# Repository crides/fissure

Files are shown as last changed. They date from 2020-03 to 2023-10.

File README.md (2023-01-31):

Fissure
=======

My Choc-only split keyboard for desktop use with constant experiments. See below for current keymap

You can find firmware, PCB design and gerber files for past versions if you want to build your own (I'm not used to version controlling PCB files, so if you have problems with them, please let me know). The firmware of this keyboard is based on [QMK firmware](https://github.com/qmk/qmk_firmware). The PCB files are in `pcb/`, and firmwares in `qmk/`.

For a list of all of the past versions, see [here](versions.md). Fun fact: only the first version has 46 keys, which came down to 36 after two weeks of using when I desoldered the top number row.

For a list of past keymaps, you'll have to do it manually as Keyboard Layout Editor doesn't support viewing versions of a keymap. Since the saved keymap is hosted on gist, you can check out [all the past versions of the gist](https://gist.github.com/crides/99409a249d886554bd60af15782b2d50/revisions), copy the contents of each file back into KLE to view the past keymaps.

## Picture of latest version (v3.2)

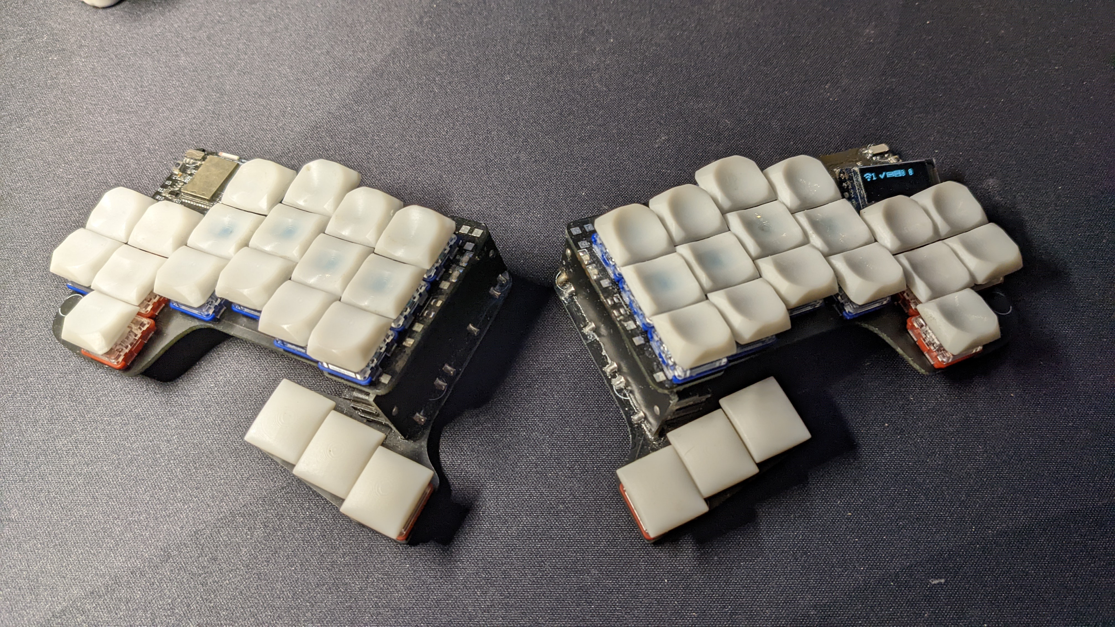
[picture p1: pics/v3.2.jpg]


## Latest Keymap

(generated using <https://github.com/caksoylar/keymap-drawer> with tweaked colors, source is in [keymap.yaml](./keymap.yaml). Note the existence of the lower outer pinky keys is a limitation of the graphic generator. [equivalent version on KLE](http://www.keyboard-layout-editor.com/#/gists/99409a249d886554bd60af15782b2d50))



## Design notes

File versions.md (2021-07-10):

# Versions

## Version 3 - low profile?

Technically none of the version 3 boards are truly 36 key, as they are 20 key reversible PCBs. However only the 2 extra on the right side are meant to be used, and they are only for stenography. So practically this can be considered a 36 key.

For v3.1 and above I have written a [build guide](build-v3.1+.md) as the design is not exactly focused on the ease to build.

### Version 3.1

The PCB construction on v3.0 is too complex for having 2 different vertical supports, and prone to unbalancing. In 3.1 this was changed to only 1 long vertical support, so that there are fewer PCB pieces needed, and balancing becomes much easier. The connector has been changed to flat solder-only connectors, as it's hard for pegs and holes to be aligned, connected, and be clean on the outside. The tenting has also been increased to 20mm instead of 15mm. I also attempted to make the board more compact by moving the TRRS connector and OLED screen. The latter was moved to the board connector in the middle as a experiment. The promicro has been moved below the board, as there are more room there, making it look better on the outside.

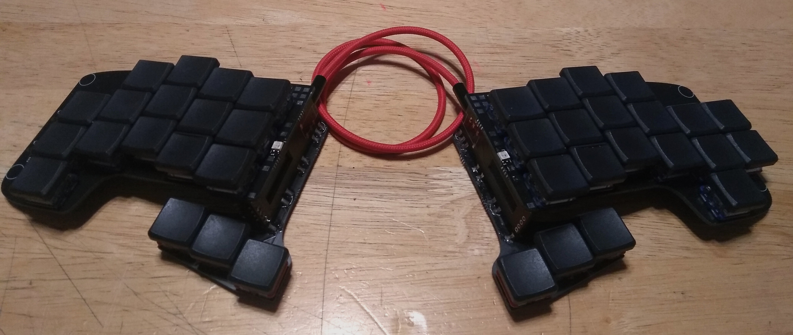
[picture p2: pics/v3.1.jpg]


### Version 3.0

As I find tented boards to be more comfortable (my palms have never been horizontal when I type), this is an attempt at a board that "automatically tents" and have different heights for the thumb and fingers. I also integrated [embedded steno](https://github.com/crides/steno) and thus the 2 added pinky switches (they are only used on the right side, as you can tell from the pictures) and the OLED for displaying the current stroke.

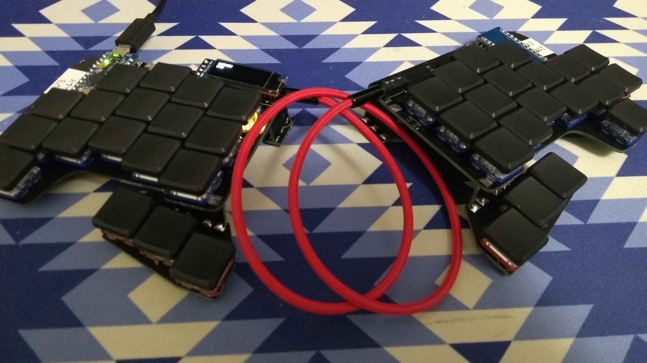
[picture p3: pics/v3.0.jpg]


## Version 2 - going smaller

A 36 key columnar-staggered version. I removed the nubmer row cuz I have dropped it in version 1. A SK6812 mini is added for status display.

The gerber files for version 2 is in a separate folder (I still need to get used to version control with external-software-managed files).

### Version 2.1

I decided that Logitech Unifying wireless is not usabily-possible, so that was dropped. Pinky stagger was increased by 2mm, and thumb cluster was rotated by 90degs so that they are closer together. Spacing was finally changed to choc spacing (17x18mm). A joystick footprint was added, but was never used due to the high force required to move the stick, and dropping 1 thumb button was quite time consuming

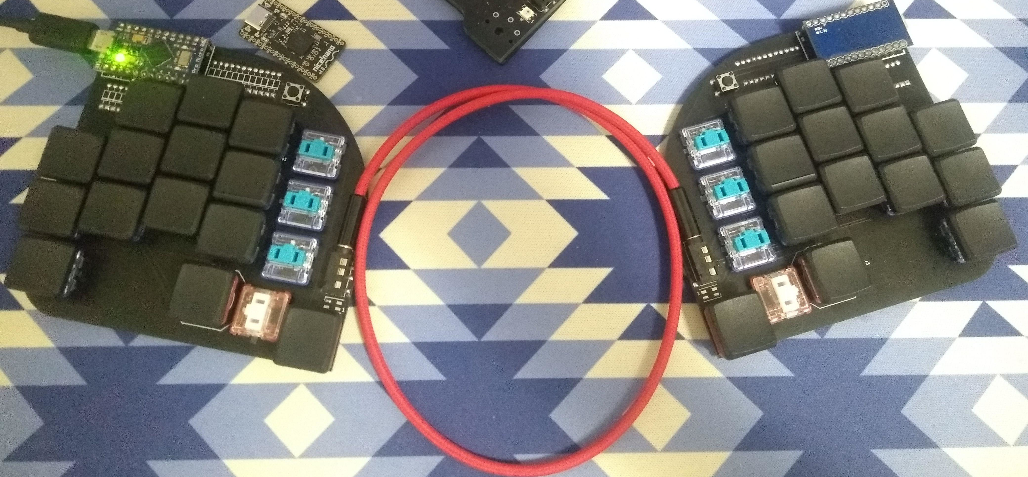
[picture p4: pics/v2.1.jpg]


### Version 2.0

I wanted to go wireless with this version, and so I added a 2x4 header footprint for a nRF24 module (for potential use with a Logitech Unifying Receiver) and a coincell localtion. Spacing was changed to slightly-above-choc (i.e. 17.5x18.5mm).

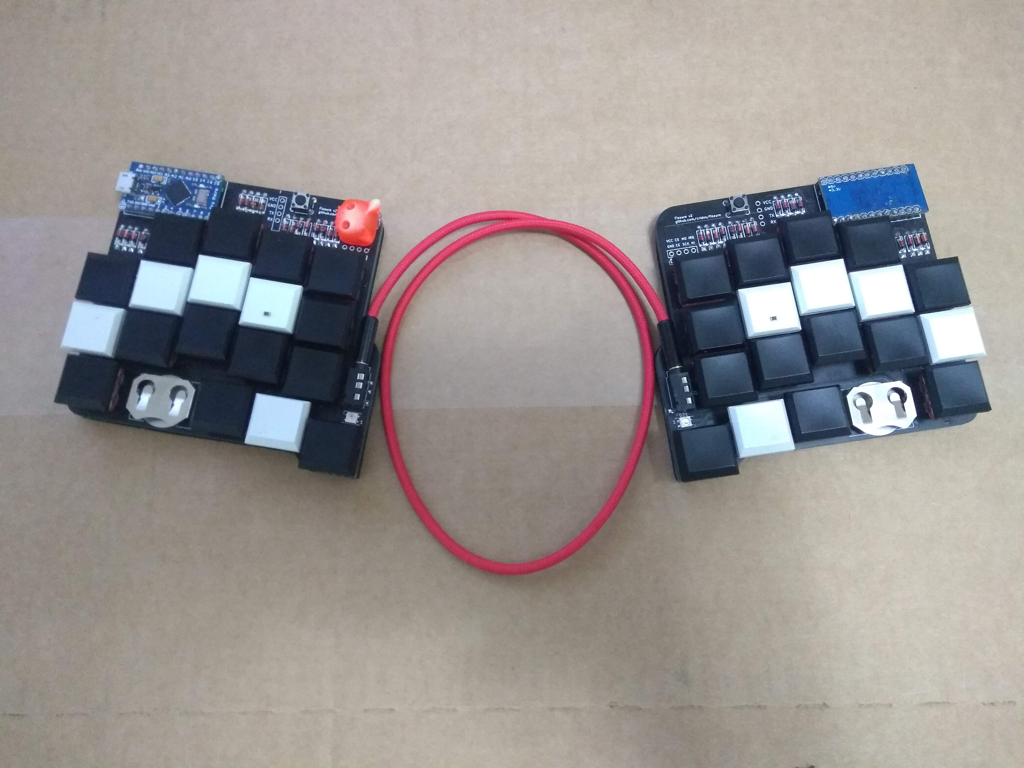
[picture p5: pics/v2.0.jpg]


## Version 1 - the start

A 46-key split keyboard that combined (in version 1) the ideas of [5plit](https://oddrocketkeyboards.blogspot.com/2018/05/5plit-v2.html) and [for science](https://github.com/peej/for-science-keyboard). This was my first ever mechanical keyboard, and I decided to go with a slightly more common layout (orthogonal & 46 key with a number row). However I quickly got rid of the number row, because it's hard for my fingers to easily reach it. It also uses MX spacing, which I quickly decided was too wide. I also botched on a RGB LED for status display.

Only firmware and gerber files are currently available, as I lost my design files when I accidentally deleted them (and I used no VCS at that time :)).

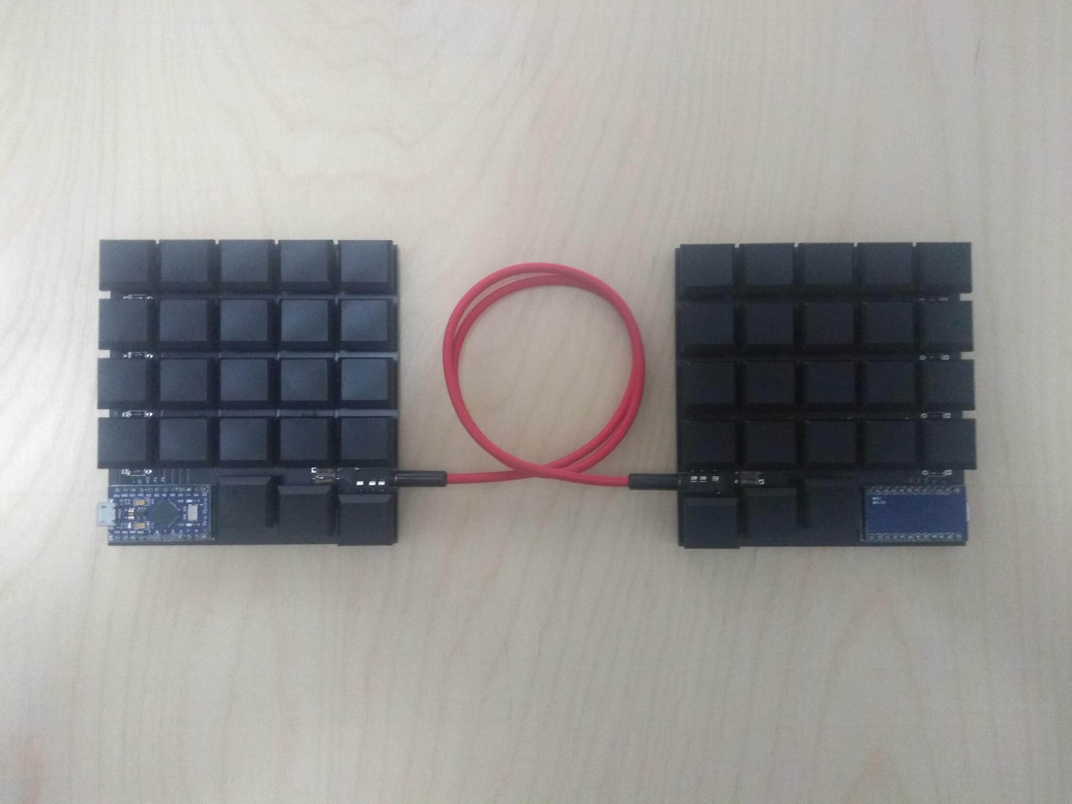
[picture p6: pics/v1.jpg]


[keymap](http://www.keyboard-layout-editor.com/#/gists/f470cb5798ff4dc8b27f680a605061f3).

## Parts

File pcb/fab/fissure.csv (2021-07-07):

Comment | Designator | Footprint | LCSC Part #
10nF | C1 | C_0603_1608Metric
BLUE | D1 | LED_1206_3216Metric
1N5819 | D3 | D_SOD-323
RED | D5 | LED_1206_3216Metric
USB_C_Receptacle_USB2.0 | J2 | USB_C_Receptacle_HRO_TYPE-C-31-M-12
AO3401A | Q1,Q2 | SOT-23
10k | R10 | R_0603_1608Metric
2M | R11 | R_0603_1608Metric
100k | R12 | R_0603_1608Metric
5.1M | R5,R8 | R_0603_1608Metric
1k | R6,R4 | R_0603_1608Metric
5.1k | R7,R9 | R_0603_1608Metric
SW_Push | SW1 | SW_SPST_B3U-1000P
SW_SPDT | SW4 | SW_SPDT_PCM12
LTC4054ES5-4.2 | U3 | TSOT-23-5
MCP1700-3302E_SOT23 | U4 | SOT-23

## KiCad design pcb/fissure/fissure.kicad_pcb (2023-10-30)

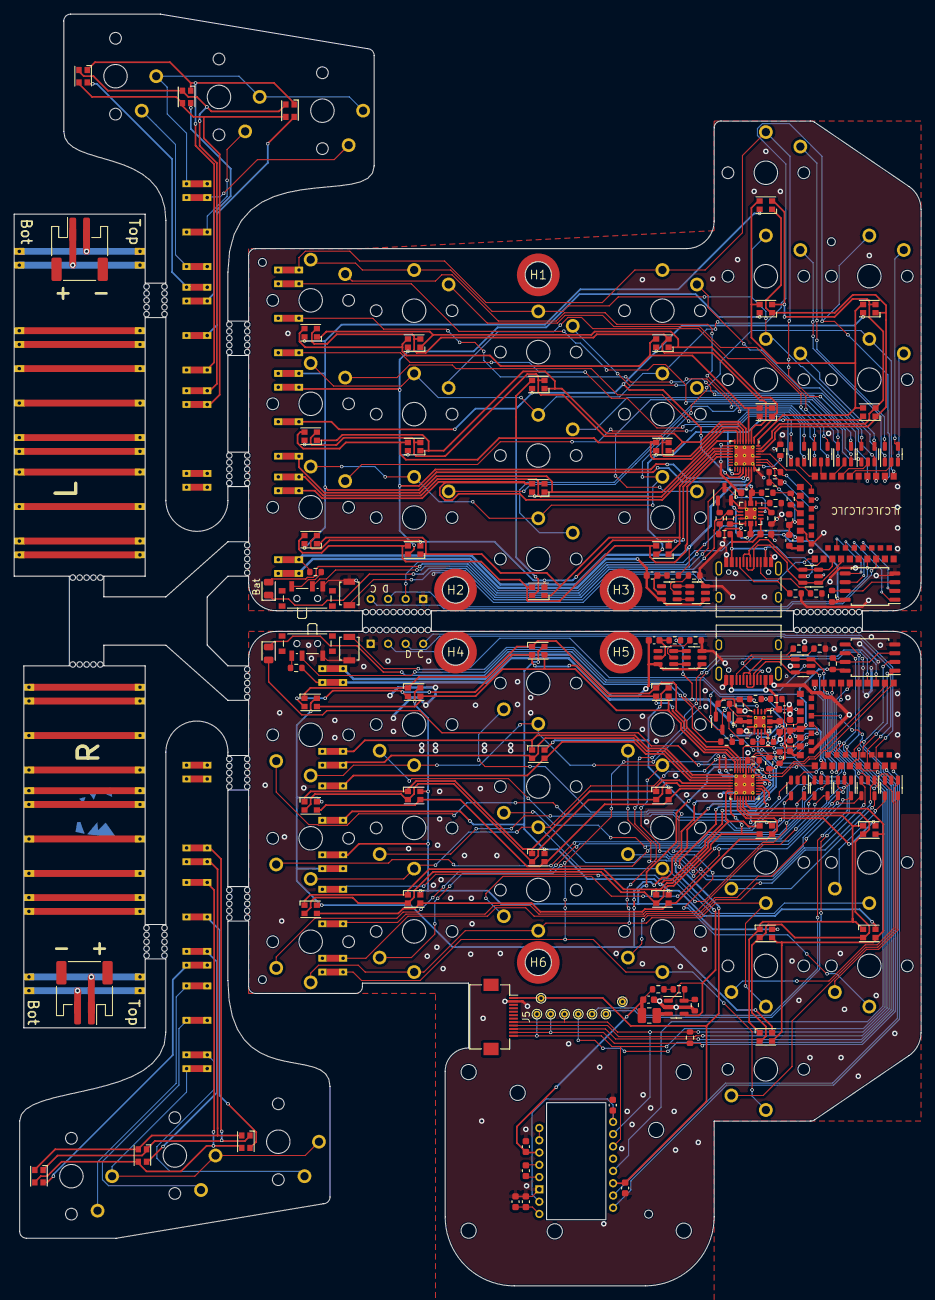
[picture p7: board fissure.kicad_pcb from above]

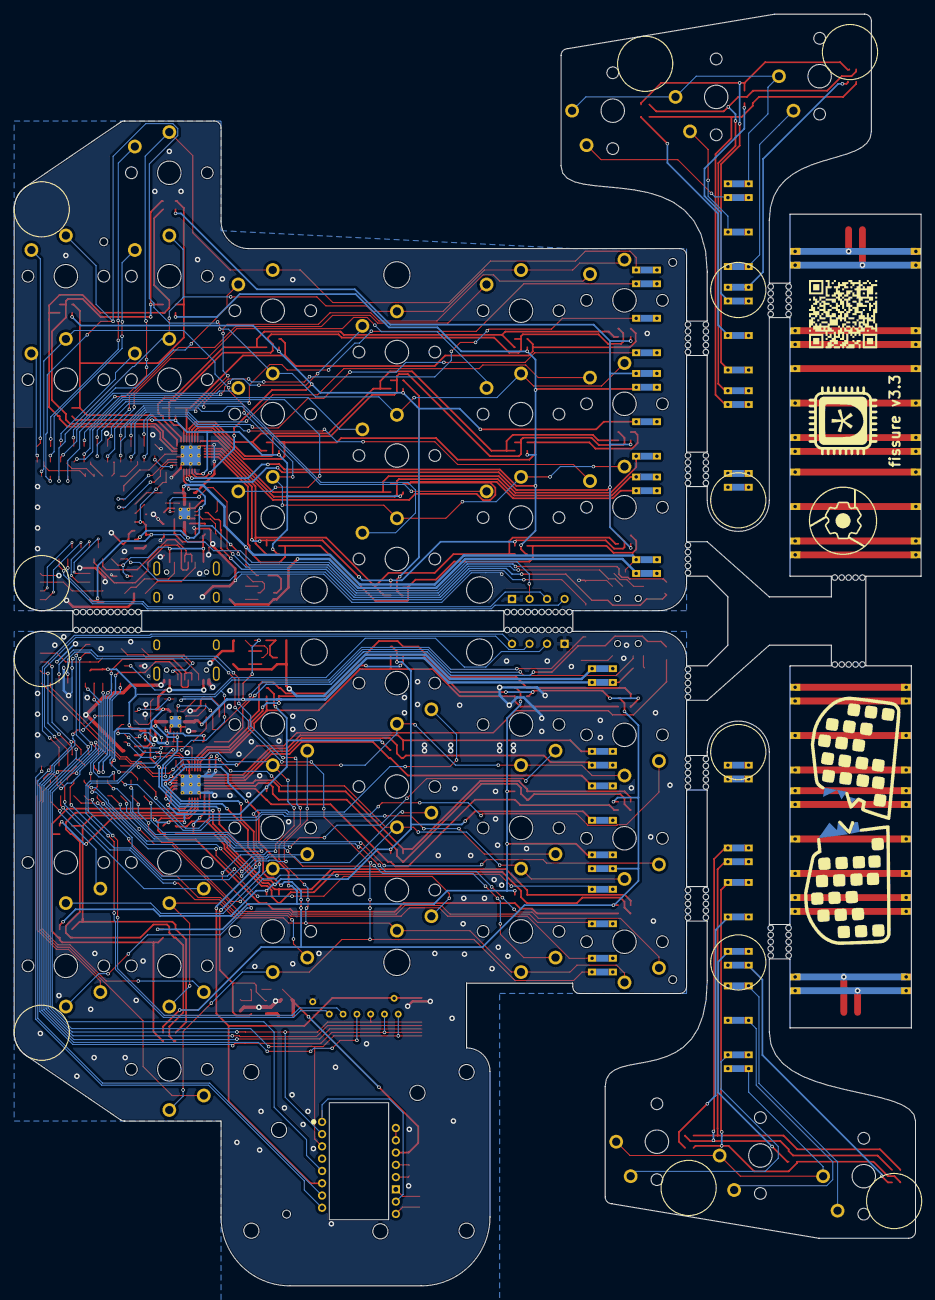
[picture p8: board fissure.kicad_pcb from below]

Board: 2 copper layers, 131.5 x 184.4 mm, 200 parts (6 on the bottom side), 228 nets.

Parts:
BT1, BT2: Battery_Cell; JST_PH_S2B-PH-SM4-TB_1x02-1MP_P2.00mm_Horizontal
C1, C2, C3, C4, C5, C13, C14, C15: 4.7uF; C_0603_1608Metric
C6, C7, C8: 100nF; C_0603_1608Metric
C9, C11: 10nF; C_0603_1608Metric
C10, C12: 10uF; C_0603_1608Metric
C16, C17: 0.1uF; C_0603_1608Metric
D1, D2: RED; LED_0805_2012Metric
D3, D4, D5, D6, D7, D8, D9, D10, D11, D12: 1SS309; SOT-23-5
H1, H2, H3, H4, H5, H6: M2
J1, J9: debug-port; debug-port-single-side
J2, J8: USB_C_Receptacle_USB2.0; USB_C_Receptacle_HRO_TYPE-C-31-M-12
J3, J4, J12, J16: Conn_01x12_Pin; bridge-conn
J5: cirque-trackpad; Hirose_FH12-12S-0.5SH_1x12-1MP_P0.50mm_Horizontal
J6, J7, J11, J17: Conn_01x12_Socket; bridge
K1, K6, K11, K16, K17, K25, K30, K35, K36, K37: diode-choc; pg1350-SN
K2, K5, K7, K10, K12, K15, K22, K27, K32: diode-choc; pg1350-SL
K3, K8, K13, K18, K19, K20, K23, K28, K33, K38, K39, K40: diode-choc; pg1350-S
K4, K9, K14, K21, K24, K26, K29, K31, K34: diode-choc; pg1350-SR
L1, L3: 10uH; L_0603_1608Metric
L2: 2.2uH; L_1008_2520Metric
LED1, LED2, LED3, LED4, LED5, LED6, LED7, LED8, LED9, LED10, LED11, LED12, LED13, LED14, LED15, LED16, LED17, LED18, LED19, LED20, LED21, LED22, LED23, LED24, LED25, LED26, LED27, LED28, LED29, LED30, LED31, LED32, LED33, LED34, LED35, LED36, LED37, LED38, LED39, LED40: LED_BGRA; LED_ASMB-KTF0-0A306
Q1, Q2: AO3400A; SOT-23
QR*****: github
R1, R2, R4, R15, R16, R22, R23: 10k; R_0603_1608Metric
R3, R5, R8, R10, R11, R12, R18, R19, R20, R21, R24, R25, R26: 100k; R_0603_1608Metric
R6, R17, R27, R28, R33, R34: 1k; R_0603_1608Metric
R7, R9, R13, R14, R29, R30, R35, R36: 5.1k; R_0603_1608Metric
R31, R32: 100; R_0603_1608Metric
SW1, SW2: SW_Push; SW_SPST_B3U-1000P
SW3, SW4: SW_SPDT; SW_SPDT_PCM12
TP1: CS; TestPoint_THTPad_D1.0mm_Drill0.5mm
TP2: SCLK; TestPoint_THTPad_D1.0mm_Drill0.5mm
TP3: MISO; TestPoint_THTPad_D1.0mm_Drill0.5mm
TP4: MOSI; TestPoint_THTPad_D1.0mm_Drill0.5mm
TP5: SDA; TestPoint_THTPad_D1.0mm_Drill0.5mm
TP6: SCL; TestPoint_THTPad_D1.0mm_Drill0.5mm
TP7: 3V3; TestPoint_THTPad_D1.0mm_Drill0.5mm
TP8: GND; TestPoint_THTPad_D1.0mm_Drill0.5mm
U1, U12: e73-2gm08s1c; e73-2g4m08s1c-shrunk
U2, U10: W25Q128JVS; SOIC-8_5.23x5.23mm_P1.27mm
U3, U9: BQ24075; VQFN-16-1EP_3x3mm_P0.5mm_EP1.68x1.68mm_ThermalVias
U4: TLV62568DBV; SOT-23-5
U5: PMW3610
U6, U13: IS31FL3729; QFN-32-1EP_4x4mm_P0.4mm_EP2.9x2.9mm_ThermalVias
U7, U8: SRV05-4; SOT-23-6
U11, U14: DW01A; SOT-23-6
U15, U16: FS8205; SOT-23-6

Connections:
+1V8: C7.2, C12.2, L2.2, R10.1, U5.14 (VDD)
/power_l/BAT_PULLUP: R21.1, SW4.1 (A)
/power_l/SYSOFF: Q1.3 (D), SW4.2 (B), U3.15 (SYSOFF)
/power_l/~PGOOD: R25.1, R27.1, U3.7 (~PGOOD)
/power_r/BAT_PULLUP: R24.1, SW3.3 (C)
/power_r/SYSOFF: Q2.3 (D), SW3.2 (B), U9.15 (SYSOFF)
/power_r/~PGOOD: R26.1, R28.1, U9.7 (~PGOOD)
/thumb+led_l/A0: LED1.4 (A), LED2.4 (A), LED7.4 (A), LED8.4 (A), LED16.4 (A), U6.19 (SW4)
/thumb+led_l/A1: J3.7, LED3.4 (A), LED12.4 (A), LED13.4 (A), LED17.4 (A), U6.20 (SW3)
/thumb+led_l/A2: J3.6, LED4.4 (A), LED6.4 (A), LED9.4 (A), LED14.4 (A), U6.21 (SW2)
/thumb+led_l/A3: J3.5, LED5.4 (A), LED10.4 (A), LED11.4 (A), LED15.4 (A), U6.22 (SW1)
/thumb+led_l/B0: LED6.1 (BK), LED11.1 (BK), LED16.1 (BK), LED17.1 (BK), U6.30 (CS1)
/thumb+led_l/B1: LED1.1 (BK), LED12.1 (BK), LED14.1 (BK), LED15.1 (BK), U6.1 (CS4)
/thumb+led_l/B2: LED7.1 (BK), LED9.1 (BK), LED10.1 (BK), LED13.1 (BK), U6.4 (CS7)
/thumb+led_l/B3: LED2.1 (BK), LED3.1 (BK), LED4.1 (BK), LED5.1 (BK), U6.11 (CS13)
/thumb+led_l/B4: J3.8, LED8.1 (BK), U6.7 (CS10)
/thumb+led_l/G0: LED6.2 (GK), LED11.2 (GK), LED16.2 (GK), LED17.2 (GK), U6.31 (CS2)
/thumb+led_l/G1: LED1.2 (GK), LED12.2 (GK), LED14.2 (GK), LED15.2 (GK), U6.2 (CS5)
/thumb+led_l/G2: LED7.2 (GK), LED9.2 (GK), LED10.2 (GK), LED13.2 (GK), U6.5 (CS8)
/thumb+led_l/G3: LED2.2 (GK), LED3.2 (GK), LED4.2 (GK), LED5.2 (GK), U6.12 (CS14)
/thumb+led_l/G4: J3.9, LED8.2 (GK), U6.8 (CS11)
/thumb+led_l/R0: LED6.3 (RK), LED11.3 (RK), LED16.3 (RK), LED17.3 (RK), U6.32 (CS3)
/thumb+led_l/R1: LED1.3 (RK), LED12.3 (RK), LED14.3 (RK), LED15.3 (RK), U6.3 (CS6)
/thumb+led_l/R2: LED7.3 (RK), LED9.3 (RK), LED10.3 (RK), LED13.3 (RK), U6.6 (CS9)
/thumb+led_l/R3: LED2.3 (RK), LED3.3 (RK), LED4.3 (RK), LED5.3 (RK), U6.13 (CS15)
/thumb+led_l/R4: J3.10, LED8.3 (RK), U6.10 (CS12)
/thumb+led_l/T_A1: J4.7, LED20.4 (A)
/thumb+led_l/T_A2: J4.6, LED19.4 (A)
/thumb+led_l/T_A3: J4.5, LED18.4 (A)
/thumb+led_l/T_B4: J4.8, LED18.1 (BK), LED19.1 (BK), LED20.1 (BK)
/thumb+led_l/T_G4: J4.9, LED18.2 (GK), LED19.2 (GK), LED20.2 (GK)
/thumb+led_l/T_R4: J4.10, LED18.3 (RK), LED19.3 (RK), LED20.3 (RK)
/thumb+led_r/A0: LED24.4 (A), LED25.4 (A), LED28.4 (A), LED29.4 (A), LED37.4 (A), U13.19 (SW4)
/thumb+led_r/A1: J12.7, LED23.4 (A), LED33.4 (A), LED34.4 (A), LED36.4 (A), U13.20 (SW3)
/thumb+led_r/A2: J12.6, LED22.4 (A), LED27.4 (A), LED30.4 (A), LED32.4 (A), U13.21 (SW2)
/thumb+led_r/A3: J12.5, LED21.4 (A), LED26.4 (A), LED31.4 (A), LED35.4 (A), U13.22 (SW1)
/thumb+led_r/B0: LED21.1 (BK), LED22.1 (BK), LED23.1 (BK), LED24.1 (BK), U13.30 (CS1)
/thumb+led_r/B1: LED26.1 (BK), LED27.1 (BK), LED29.1 (BK), LED33.1 (BK), U13.4 (CS7)
/thumb+led_r/B2: LED25.1 (BK), LED31.1 (BK), LED32.1 (BK), LED34.1 (BK), U13.7 (CS10)
/thumb+led_r/B3: LED30.1 (BK), LED35.1 (BK), LED36.1 (BK), LED37.1 (BK), U13.11 (CS13)
/thumb+led_r/B4: J12.10, LED28.1 (BK), U13.1 (CS4)
/thumb+led_r/G0: LED21.2 (GK), LED22.2 (GK), LED23.2 (GK), LED24.2 (GK), U13.31 (CS2)
/thumb+led_r/G1: LED26.2 (GK), LED27.2 (GK), LED29.2 (GK), LED33.2 (GK), U13.5 (CS8)
/thumb+led_r/G2: LED25.2 (GK), LED31.2 (GK), LED32.2 (GK), LED34.2 (GK), U13.8 (CS11)
/thumb+led_r/G3: LED30.2 (GK), LED35.2 (GK), LED36.2 (GK), LED37.2 (GK), U13.12 (CS14)
/thumb+led_r/G4: J12.9, LED28.2 (GK), U13.2 (CS5)
/thumb+led_r/R0: LED21.3 (RK), LED22.3 (RK), LED23.3 (RK), LED24.3 (RK), U13.32 (CS3)
/thumb+led_r/R1: LED26.3 (RK), LED27.3 (RK), LED29.3 (RK), LED33.3 (RK), U13.6 (CS9)
/thumb+led_r/R2: LED25.3 (RK), LED31.3 (RK), LED32.3 (RK), LED34.3 (RK), U13.10 (CS12)
/thumb+led_r/R3: LED30.3 (RK), LED35.3 (RK), LED36.3 (RK), LED37.3 (RK), U13.13 (CS15)
/thumb+led_r/R4: J12.8, LED28.3 (RK), U13.3 (CS6)
/thumb+led_r/T_A1: J16.7, LED40.4 (A)
/thumb+led_r/T_A2: J16.6, LED39.4 (A)
/thumb+led_r/T_A3: J16.5, LED38.4 (A)
/thumb+led_r/T_B4: J16.10, LED38.1 (BK), LED39.1 (BK), LED40.1 (BK)
/thumb+led_r/T_G4: J16.9, LED38.2 (GK), LED39.2 (GK), LED40.2 (GK)
/thumb+led_r/T_R4: J16.8, LED38.3 (RK), LED39.3 (RK), LED40.3 (RK)
L_3V3: C1.1, J1.2 (3V3), L3.2, R3.2, R29.2, R30.2, U2.8 (VCC), U12.19 (VDD)
L_BAT+: C4.1, J3.11, R5.1, R21.2, R31.2, U3.2 (BAT), U3.3 (BAT)
L_BAT-: C16.2, J3.12, U11.6 (VSS), U15.1 (S1)
L_BAT_MEAS: R5.2, R8.1, U12.15 (A3_P0.05)
L_BAT_MEAS_EN: R8.2, U12.17 (P1.09)
L_COL0: D3.2 (K), U12.6 ([L]_P1.13)
L_COL1: D4.2 (K), U12.7 ([L]_A0_P0.02)
L_COL2: D5.2 (K), U12.8 ([L]_A5_P0.29)
L_COL3: D6.2 (K), U12.9 ([L]_A7_P0.31)
L_COL4: D7.2 (K), U12.10 ([L]_A6_P0.30)
L_CS: U2.1 (~CS), U12.34 (P0.22)
L_D+: J2.A6 (D+), J2.B6 (D+), U8.1 (IO1), U8.6 (IO4), U12.31 (D+)
L_D-: J2.A7 (D-), J2.B7 (D-), U8.3 (IO2), U8.4 (IO3), U12.29 (D-)
L_GND: C1.2, C2.2, C3.1, C4.2, C5.2, C6.1, C7.1, C9.2, C10.2, C11.2, C12.1, C13.2, C14.1, C15.2, J1.1 (GND), J2.A1 (GND), J2.A12 (GND), J2.B1 (GND), J2.B12 (GND), J5.2 (GND), J8.A1 (GND), J8.A12 (GND), J8.B1 (GND), J8.B12 (GND), J9.1 (GND), Q1.2 (S), Q2.2 (S), R1.2, R2.2, R7.1, R9.1, R12.1, R13.1, R14.1, R15.2, R16.2, R22.1, R23.1, R33.2, R34.2, SW1.2, SW2.2, SW3.1 (A), SW4.3 (C), TP8.1, U1.5 (GND), U1.21 (GND), U1.24 (GND), U2.4 (GND), U3.4 (~CE), U3.5 (EN2), U3.8 (VSS), U3.17 (PAD), U4.2 (GND), U5.11 (GND), U6.9 (GND), U6.24 (GND), U6.28 (AD), U6.33 (GND), U7.2 (VN), U8.2 (VN), U9.4 (~CE), U9.5 (EN2), U9.8 (VSS), U9.17 (PAD), U10.4 (GND), U12.5 (GND), U12.21 (GND), U12.24 (GND), U13.9 (GND), U13.24 (GND), U13.28 (AD), U13.33 (GND), U15.3 (S2), U16.3 (S2)
L_LED_SHDN: U6.29 (~SDB), U12.12 (P0.26)
L_MISO: U2.2 (DO(IO1)), U12.36 (P1.00)
L_MOSI: U2.5 (DI(IO0)), U12.30 (P0.17)
L_ROW0: K2.1, K3.1, K4.1, K5.1, K16.1, U12.1 ([L]_P1.11)
L_ROW1: K7.1, K8.1, K9.1, K10.1, K17.1, U12.2 ([L]_P1.10)
L_ROW2: K1.1, K6.1, K13.1, K14.1, K15.1, U12.3 ([L]_A1_P0.03)
L_ROW3: J3.1, K11.1, K12.1, U12.4 ([L]_A4_P0.28)
L_RST: SW1.1, U12.26 (Reset/P0.18)
L_SCL: R30.1, U6.27 (SCL), U12.14 (P0.06)
L_SCLK: U2.6 (CLK), U12.32 (P0.20)
L_SDA: R29.1, U6.26 (SDA), U12.16 (P0.08)
L_SWC: J1.4 (SWC), U12.39 (SWC)
L_SWD: J1.3 (SWD), U12.37 (SWD)
L_VBUS: C2.1, J2.A4 (VBUS), J2.A9 (VBUS), J2.B4 (VBUS), J2.B9 (VBUS), R25.2, U3.13 (IN), U8.5 (VP), U12.27 (VBUS)
L_VDDH: C3.2, D1.2 (A), U3.6 (EN1), U3.10 (OUT), U3.11 (OUT), U6.23 (VCC), U12.23 (VDDH)
MOTION: U1.43 ([L]_P0.10), U5.8 (MOTION)
MOUSE_~CS: U1.28 (P0.15), U5.5 (~CS)
MOUSE_~RST: U1.41 ([L]_P0.09), U5.7 (~RESET)
unnamed: BT1.1 (+), J6.11, J7.11
unnamed: BT1.2 (-), J6.12, J7.12
unnamed: BT2.1 (+), J11.11, J17.11
unnamed: BT2.2 (-), J11.12, J17.12
unnamed: D1.1 (K), R6.2
unnamed: D2.1 (K), R17.2
unnamed: D3.1 (A), K6.2
unnamed: D3.3 (A), K16.2
unnamed: D3.4 (A), K17.2
unnamed: D3.5 (A), K11.2
unnamed: D4.1 (A), K2.2
unnamed: D4.3 (A), K7.2
unnamed: D4.4 (A), K1.2
unnamed: D4.5 (A), K12.2
unnamed: D5.1 (A), K3.2
unnamed: D5.3 (A), K8.2
unnamed: D5.4 (A), K13.2
unnamed: D5.5 (A), J3.2
unnamed: D6.1 (A), K4.2
unnamed: D6.3 (A), K9.2
unnamed: D6.4 (A), K14.2
unnamed: D6.5 (A), J3.3
unnamed: D7.1 (A), K5.2
unnamed: D7.3 (A), K10.2
unnamed: D7.4 (A), K15.2
unnamed: D7.5 (A), J3.4
unnamed: D8.1 (A), K23.2
unnamed: D8.3 (A), K28.2
unnamed: D8.4 (A), K33.2
unnamed: D8.5 (A), J12.2
unnamed: D9.1 (A), K22.2
unnamed: D9.3 (A), K27.2
unnamed: D9.4 (A), K32.2
unnamed: D9.5 (A), J12.3
unnamed: D10.1 (A), K31.2
unnamed: D10.3 (A), K21.2
unnamed: D10.4 (A), K26.2
unnamed: D10.5 (A), J12.4
unnamed: D11.1 (A), K35.2
unnamed: D11.3 (A), K30.2
unnamed: D11.4 (A), K36.2
unnamed: D11.5 (A), K37.2
unnamed: D12.1 (A), K34.2
unnamed: D12.3 (A), K29.2
unnamed: D12.4 (A), K24.2
unnamed: D12.5 (A), K25.2
unnamed: J2.A5 (CC1), R7.2
unnamed: J2.B5 (CC2), R9.2
unnamed: J4.1, K18.1, K19.1, K20.1
unnamed: J4.2, K20.2
unnamed: J4.3, K19.2
unnamed: J4.4, K18.2
unnamed: J6.1, J7.1
unnamed: J6.2, J7.2
unnamed: J6.3, J7.3
unnamed: J6.4, J7.4
unnamed: J6.5, J7.5
unnamed: J6.6, J7.6
unnamed: J6.7, J7.7
unnamed: J6.8, J7.8
unnamed: J6.9, J7.9
unnamed: J6.10, J7.10
unnamed: J8.A5 (CC1), R13.2
unnamed: J8.B5 (CC2), R14.2
unnamed: J11.1, J17.1
unnamed: J11.2, J17.2
unnamed: J11.3, J17.3
unnamed: J11.4, J17.4
unnamed: J11.5, J17.5
unnamed: J11.6, J17.6
unnamed: J11.7, J17.7
unnamed: J11.8, J17.8
unnamed: J11.9, J17.9
unnamed: J11.10, J17.10
unnamed: J16.1, K38.1, K39.1, K40.1
unnamed: J16.2, K40.2
unnamed: J16.3, K39.2
unnamed: J16.4, K38.2
unnamed: Q1.1 (G), R27.2
unnamed: Q2.1 (G), R28.2
unnamed: R10.2, R11.1
unnamed: L1.1, U1.25 (DCCH)
unnamed: R3.1, U2.3 (IO2), U2.7 (IO3)
unnamed: R2.1, U3.16 (ISET)
unnamed: R1.1, U3.1 (TS)
unnamed: R6.1, U3.9 (~CHG)
unnamed: R11.2, R12.2, U4.5 (FB)
unnamed: L2.1, U4.3 (SW)
unnamed: C9.1, U5.1 (+VCSEL), U5.10 (PASS_T)
unnamed: U5.15 (XYLASER), U5.16 (-VCSEL)
unnamed: C8.2, U5.12 (C+)
unnamed: C8.1, U5.13 (C-)
unnamed: C10.1, C11.1, U5.9 (VCP)
unnamed: R22.2, U6.25 (ISET)
unnamed: R16.1, U9.16 (ISET)
unnamed: R15.1, U9.1 (TS)
unnamed: R17.1, U9.9 (~CHG)
unnamed: R20.1, U10.3 (IO2), U10.7 (IO3)
unnamed: R33.1, U11.2 (CSI)
unnamed: U11.3 (OC), U15.4 (G2)
unnamed: U11.1 (OD), U15.6 (G1)
unnamed: C16.1, R31.1, U11.5 (VDD)
unnamed: L3.1, U12.25 (DCCH)
unnamed: R23.2, U13.25 (ISET)
unnamed: R34.1, U14.2 (CSI)
unnamed: U14.3 (OC), U16.4 (G2)
unnamed: U14.1 (OD), U16.6 (G1)
unnamed: C17.1, R32.1, U14.5 (VDD)
R_3V3: C5.1, C6.2, J5.1 (3V3), J9.2 (3V3), L1.2, R20.2, R35.2, R36.2, TP7.1, U1.19 (VDD), U5.6 (VDDIO), U10.8 (VCC)
R_BAT+: C15.1, J12.11, R18.1, R24.2, R32.2, U9.2 (BAT), U9.3 (BAT)
R_BAT-: C17.2, J12.12, U14.6 (VSS), U16.1 (S1)
R_BAT_MEAS: R18.2, R19.1, U1.15 (A3_P0.05)
R_BAT_MEAS_EN: R19.2, U1.17 (P1.09)
R_COL0: D11.2 (K), U1.6 ([L]_P1.13)
R_COL1: D12.2 (K), U1.7 ([L]_A0_P0.02)
R_COL2: D8.2 (K), U1.8 ([L]_A5_P0.29)
R_COL3: D9.2 (K), U1.9 ([L]_A7_P0.31)
R_COL4: D10.2 (K), U1.10 ([L]_A6_P0.30)
R_CS: U1.36 (P1.00), U10.1 (~CS)
R_CS3: TP1.1, U1.16 (P0.08)
R_D+: J8.A6 (D+), J8.B6 (D+), U1.31 (D+), U7.1 (IO1), U7.6 (IO4)
R_D-: J8.A7 (D-), J8.B7 (D-), U1.29 (D-), U7.3 (IO2), U7.4 (IO3)
R_LED_SHDN: U1.18 (A2_P0.04), U13.29 (~SDB)
R_MISO: J5.11 (MISO), R4.2, TP3.1, U1.34 (P0.22), U10.2 (DO(IO1))
R_MOSI: J5.8 (MOSI), R4.1, TP4.1, U1.32 (P0.20), U5.2 (SDIO), U10.5 (DI(IO0))
R_ROW0: K21.1, K22.1, K23.1, K24.1, K37.1, U1.1 ([L]_P1.11)
R_ROW1: K26.1, K27.1, K28.1, K29.1, K36.1, U1.2 ([L]_P1.10)
R_ROW2: K25.1, K30.1, K31.1, K32.1, K33.1, U1.3 ([L]_A1_P0.03)
R_ROW3: J12.1, K34.1, K35.1, U1.4 ([L]_A4_P0.28)
R_RST: SW2.1, U1.26 (Reset/P0.18)
R_SCL: R36.1, TP6.1, U1.20 (P0.12), U13.27 (SCL)
R_SCLK: J5.12 (SCK), TP2.1, U1.30 (P0.17), U5.3 (SCLK), U10.6 (CLK)
R_SDA: R35.1, TP5.1, U1.22 (P0.07), U13.26 (SDA)
R_SWC: J9.4 (SWC), U1.39 (SWC)
R_SWD: J9.3 (SWD), U1.37 (SWD)
R_VBUS: C13.1, J8.A4 (VBUS), J8.A9 (VBUS), J8.B4 (VBUS), J8.B9 (VBUS), R26.2, U1.27 (VBUS), U7.5 (VP), U9.13 (IN)
R_VDDH: C14.2, D2.2 (A), U1.23 (VDDH), U4.1 (EN), U4.4 (VIN), U9.6 (EN1), U9.10 (OUT), U9.11 (OUT), U13.23 (VCC)
TP_DR: J5.9 (DR), U1.33 (P0.13)
TP_~CS: J5.10 (SS), U1.35 (P0.24)

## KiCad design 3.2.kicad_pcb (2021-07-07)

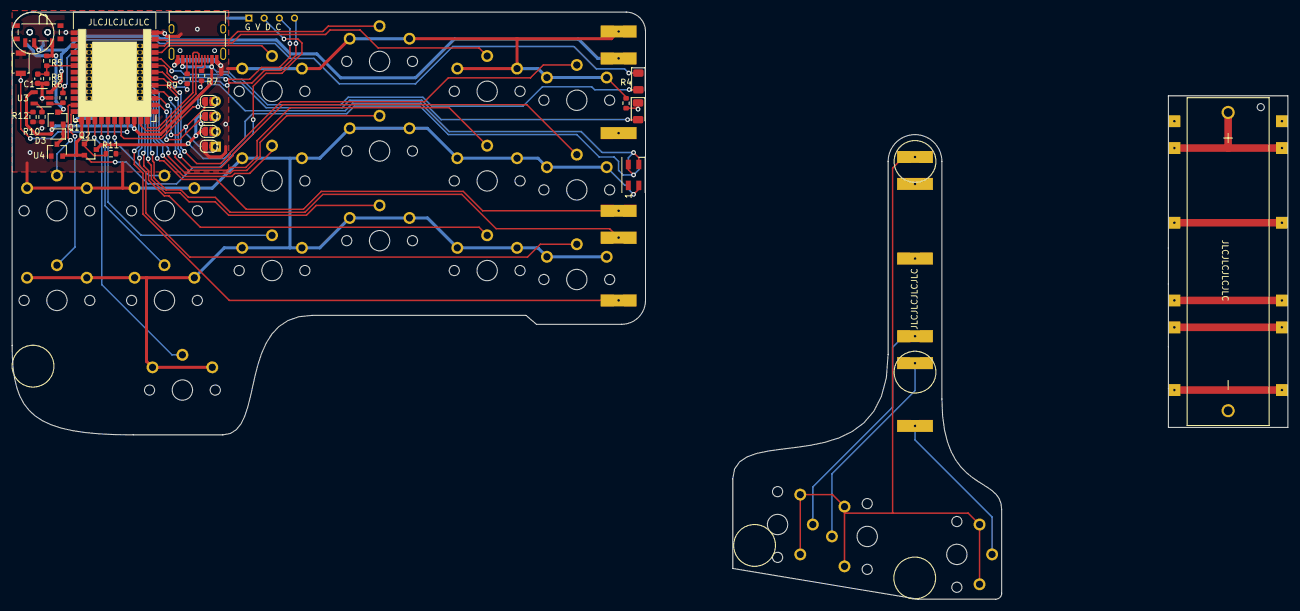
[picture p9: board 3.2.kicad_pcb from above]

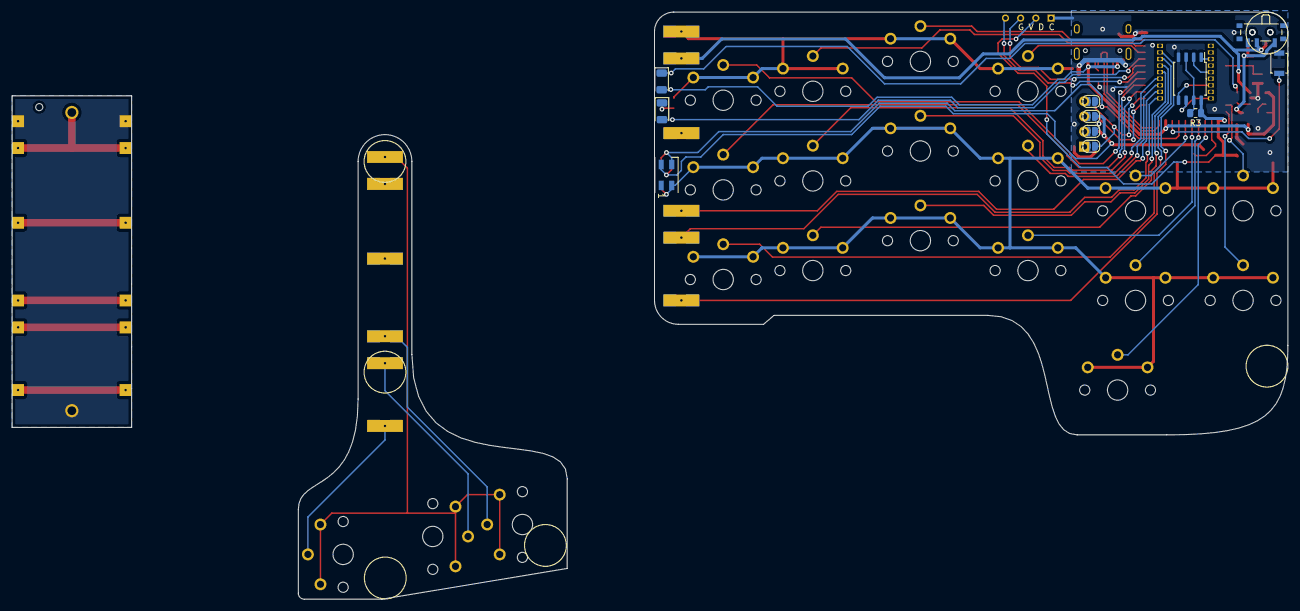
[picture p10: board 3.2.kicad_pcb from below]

Board: 2 copper layers, 106.0 x 70.8 mm, 64 parts (13 on the bottom side), 63 nets.

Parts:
BT1: Battery_Cell; BA1AAAPC
C1: 10nF; C_0603_1608Metric
D1, D4: BLUE; LED_1206_3216Metric
D2, D5: RED; LED_1206_3216Metric
D3: 1N5819; D_SOD-323
D41, D42: SK6812MINI; LED_SK6812MINI_PLCC4_3.5x3.5mm_P1.75mm
J1: Conn_01x04_Female; debug-port
J2: USB_C_Receptacle_USB2.0; USB_C_Receptacle_HRO_TYPE-C-31-M-12
J3, J4: Conn_01x06; bridge-conn
J5: OLED
J6, J7: Conn_01x06; bridge
JP1, JP2, JP3, JP4, JP5, JP6, JP7, JP8: SolderJumper_2_Open; SolderJumper-2_P1.3mm_Open_RoundedPad1.0x1.5mm
K1, K2, K3, K6, K7, K8, K11, K12, K13, K16, K17, K18, K19, K20: KEY; PG1350-reversible-no-diode-short
K4, K9, K14: KEY; PG1350-reversible-no-diode-short-offcenter
K5, K10, K15: KEY; PG1350-reversible-no-diode-short-offcenter-outer
Q1, Q2: AO3401A; SOT-23
R3: 10k; R_0805_2012Metric
R4, R6: 1k; R_0603_1608Metric
R5, R8: 5.1M; R_0603_1608Metric
R7, R9: 5.1k; R_0603_1608Metric
R10: 10k; R_0603_1608Metric
R11: 2M; R_0603_1608Metric
R12: 100k; R_0603_1608Metric
SW1, SW2: SW_Push; SW_SPST_B3U-1000P
SW3, SW4: SW_SPDT; SW_SPDT_PCM12
U1: Holyiot_18010
U2: MT25QL128ABA1ESE; SOP-8_5.28x5.23mm_P1.27mm
U3: LTC4054ES5-4.2; TSOT-23-5
U4: MCP1700-3302E_SOT23; SOT-23

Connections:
BAT: J3.2, SW3.2 (B), SW4.2 (B), U3.3 (BAT)
BAT_MEAS: C1.1, R5.2, R8.1, U1.6 ([L]_AIN_P0.03)
BLUE: D1.2 (A), D4.2 (A), U1.36 ([L]_P1.04)
CS: U1.16 (P0.25), U2.1 (S#)
D+: J2.A6 (D+), J2.B6 (D+), U1.45 (D+)
D-: J2.A7 (D-), J2.B7 (D-), U1.46 (D-)
EXT_VCC: D41.4 (VDD), D42.4 (VDD), JP3.1 (A), JP6.2 (B), Q2.3 (D)
GND: C1.2, D41.2 (VSS), D42.2 (VSS), J1.1, J2.A1 (GND), J2.A12 (GND), J2.B1 (GND), J2.B12 (GND), J3.1, JP4.1 (A), JP5.2 (B), K1.2, K2.2, K3.2, K4.2, K5.2, K6.2, K7.2, K8.2, K9.2, K10.2, K11.2, K12.2, K13.2, K14.2, K15.2, K16.2, K17.2, R4.2, R7.1, R8.2, R9.1, R10.2, R11.2, R12.2, SW1.2, SW2.2, U1.1 (GND), U1.32 (GND), U1.44 (GND), U2.4 (GND), U3.2 (GND), U4.1 (GND)
K1: K1.1, U1.50 (P0.21)
K2: K2.1, U1.35 ([L]_P1.06)
K3: K3.1, U1.33 ([L]_P0.10)
K4: K4.1, U1.34 ([L]_P0.09)
K5: K5.1, U1.39 ([L]_P1.02)
K6: K6.1, U1.52 (P0.12)
K7: K7.1, U1.29 (P0.14)
K8: K8.1, U1.28 (P0.15)
K9: K9.1, U1.41 ([L]_P1.03)
K10: K10.1, U1.40 ([L]_P1.01)
K11: K11.1, U1.53 (P1.09)
K12: K12.1, U1.51 (P0.23)
K13: K13.1, U1.27 (P0.17)
K14: K14.1, U1.26 (P0.20)
K15: K15.1, U1.25 (P0.24)
K16: K16.1, U1.12 (AIN_P0.04)
K17: K17.1, U1.13 (AIN_P0.05)
K18: J3.6, U1.24 ([L]_P1.05)
K19: J3.5, U1.31 (P0.16)
K20: J3.4, U1.30 (P0.13)
MCU_BAT: Q1.3 (D), R5.1, SW3.1 (A), SW4.1 (A)
MISO_DQ1: U1.18 (P1.08), U2.2 (DQ1)
MOSI_DQ0: U1.20 (P0.08), U2.5 (DQ0)
unnamed: D1.1 (K), D4.1 (K), R4.1
unnamed: D2.1 (K), D5.1 (K), R6.1
unnamed: D3.1 (K), Q1.2 (S), U4.3 (VI)
unnamed: J2.A5 (CC1), R7.2
unnamed: J2.B5 (CC2), R9.2
unnamed: J5.1, JP4.2 (B), JP8.1 (A)
unnamed: J5.2, JP3.2 (B), JP7.1 (A)
unnamed: J5.3, JP2.2 (B), JP6.1 (A)
unnamed: J5.4, JP1.2 (B), JP5.1 (A)
unnamed: J6.3, J7.3
unnamed: J6.4, J7.4
unnamed: J6.5, J7.5
unnamed: J6.6, J7.6
unnamed: R3.2, U2.3 (W#/DQ2), U2.7 (DQ3/HOLD#)
unnamed: R6.2, U3.1 (~CHRG)
unnamed: R10.1, U3.5 (PROG)
RGB: D41.3 (DIN), D42.3 (DIN), U1.49 (P0.19)
RST: SW1.1, SW2.1, U1.48 (Reset/P0.18)
SCL: JP2.1 (A), JP7.2 (B), U1.43 (P0.22)
SCLK: U1.22 (P0.26), U2.6 (C)
SDA: JP1.1 (A), JP8.2 (B), U1.42 (P1.00)
SWC: J1.3, U1.37 (SWDCLK)
SWD: J1.4, U1.38 (SWDIO)
VBUS: D2.2 (A), D3.2 (A), D5.2 (A), J2.A4 (VBUS), J2.A9 (VBUS), J2.B4 (VBUS), J2.B9 (VBUS), Q1.1 (G), R12.1, U1.47 (VBUS), U3.4 (VCC)
VCC_SWITCH: Q2.1 (G), R11.1, U1.54 (P0.07)
VDD: J1.2, Q2.2 (S), R3.1, U1.55 (VDD/VDDH), U2.8 (VCC), U4.2 (VO)
bridge_BAT: BT1.1 (+), J6.2, J7.2
bridge_GND: BT1.2 (-), J6.1, J7.1
thumb_GND: J4.1, K18.2, K19.2, K20.2
thumb_K18: J4.6, K18.1
thumb_K19: J4.5, K19.1
thumb_K20: J4.4, K20.1

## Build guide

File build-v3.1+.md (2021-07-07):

# Simple build guide for Fissure v3.1

This version of the board isn't really designed with easy assembly in mind, and the order of building is really important. If you mess it up, things are harder but not impossible to fix.

## BOM

The number of switches is dependent on how many you want to have. The board is designed around a 36-key keyboard, and the extra 2 key outside of the pinky column is only used for the right side for steno. Thus I only use 38 keys myself, but you can really do anything between 36 and 40. I'll assume 40 below.

Basics:
40 x choc PG1350
40 x 1N4148 diode in SOD-123 package. I used [these](https://www.digikey.com/en/products/detail/diodes-incorporated/1N4148W-13-F/2242774)
 2 x PJ-320D TRRS jack
 2 x promicro (and probably sockets)
 2 x EVQQ2 reset buttons. I used [these](https://www.digikey.com/en/products/detail/panasonic-electronic-components/EVQ-Q2B03W/762922)
 2 x 4.7k 0805 resistors if you are not using an OLED with builtin I2C pullups. Or you can use soft serial.
 
Optional:
 1 x OLED (OLED doesn't work on the right side)
 2 x SK6812MINI Neopixels
 
I also have footprints for a MT25Q SPI NOR flash and a 10k 0805 resistor, but those are for custom embedded steno functionality, and I don't consider them publically available. Let me know if you want to use it, but it'll probably be a hassle to set up.

## Assembly

Parallel assembly can be and should be done on the individual board pieces first before final assembly.

- Alpha piece: Do it like other boards with underside promicros. Sockets first, then diodes, RGB if you have one, and reset buttons, lastly switches
- Thumb piece: Same as the alpha one. Diodes before switches
- Middle piece: OLED and TRRS jack in whatever ordering

### Final assembly

The middle piece can be angled however you want to achieve different heights and thumb-alpha positioning. I used solder balls on the alpha and thumb pieces to sort of hold the middle piece in place, before adjusting the angles. Actual steps:
- For the connector on the bottom side of the alpha piece and the top side of the thumb piece, add a lot of solder to the both pads at both ends of the connector.
- Place the middle piece between the 2, and adjust the angle to suit your hands.
- When the angle feels good, use the solder from the thumb piece to solder together the thumb and middle piece.
- Take away the alpha piece and solder the rest of the pads.
- Put the alpha piece back on top of both the middle and bottom pieces, and solder them together using the solder from the alpha piece.
- Finally flip the whole thing around and solder the rest of the pads.

## Configuration

```c
#define MATRIX_ROW_PINS { E6, B4, B5, D7 }
#define MATRIX_COL_PINS { D3, D2, F4, F5, F6 }
#define RGB_DI_PIN F7
```

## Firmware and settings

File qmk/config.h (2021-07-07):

#ifndef CONFIG_H
#define CONFIG_H

#include "config_common.h"

/* USB Device descriptor parameter */
#define VENDOR_ID       0xFEED
#define PRODUCT_ID      0x6063
#define DEVICE_VER      0x0301
#define MANUFACTURER    Crides
#define PRODUCT         Fissure-v3.1
#define DESCRIPTION     40 key split keyboard

#define USE_I2C
#define EE_HANDS
#define SPLIT_USB_DETECT

#define RGBLED_NUM 2
#define RGB_DI_PIN F7
#define RGBLED_SPLIT {1, 1}
#define RGBLIGHT_SPLIT

// Rows are doubled-up
#define MATRIX_ROWS 8
#define MATRIX_COLS 5

#define MATRIX_ROW_PINS { E6, B4, B5, D7 }
#define MATRIX_COL_PINS { D3, D2, F4, F5, F6 }

#ifdef STENO_DEBUG
#undef NO_PRINT
#endif

#define DIODE_DIRECTION COL2ROW
#define DEBOUNCING_DELAY 5
#define LOCKING_SUPPORT_ENABLE
#define LOCKING_RESYNC_ENABLE
#define PREVENT_STUCK_MODIFIERS
#define COMBO_COUNT 28
#define COMBO_TERM 60

#define STENO_DICT_MSC_PIN D4

#define LAYER_STATE_8BIT
#define NO_RESET
#define NO_ACTION_ONESHOT
#define NO_ACTION_MACRO
#define NO_ACTION_FUNCTION

#endif

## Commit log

2019-09-09 upload gerber files
    [fissure-B_Cu.gbr, fissure-B_Mask.gbr, fissure-B_SilkS.gbr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]
2019-12-12 Fissure v2
    [fissure-B_Cu.gbr, fissure-B_Mask.gbr, fissure-B_SilkS.gbr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]
2019-12-12 Footprint fixes
    [fissure-B_Cu.gbr, fissure-B_Mask.gbr, fissure-B_SilkS.gbr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]
2019-12-22 Update README and PCB files
    [fissure-B_Cu.gbr, fissure-B_Mask.gbr, fissure-B_SilkS.gbr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]
2020-01-25 Added v2 firmware
    [fissure-Edge_Cuts.gbr]
2020-03-16 Fissure pcb v2.1
    [fissure-B_Cu.gbr, fissure-B_Mask.gbr, fissure-B_SilkS.gbr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]
2020-03-19 Optimized component placement and routing
    [fissure-B_Cu.gbr, fissure-B_Mask.gbr, fissure-B_SilkS.gbr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]
2020-03-19 Rotated switches
    [fissure-B_Cu.gbr, fissure-B_Mask.gbr, fissure-B_SilkS.gbr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]
2020-03-19 Small fix
    [fissure-B_Cu.gbr, fissure-B_Mask.gbr, fissure-B_SilkS.gbr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]
2020-03-21 Added v1 gerber files
    [fissure-B_Cu.gbr, fissure-B_Mask.gbr, fissure-B_SilkS.gbr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]
2020-03-21 Added v2 gerbers
    [fissure-B_Cu.gbr, fissure-B_Mask.gbr, fissure-B_SilkS.gbr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]
2020-06-12 Cut down README
2020-07-12 v2.1 final
    [fissure-B_Cu.gbr, fissure-B_Mask.gbr, fissure-B_SilkS.gbr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]
2020-08-24 New PCB version
    - merge steno and split (no storage yet)
    - experimental lower layer thumb cluster
    - moved pro micro location
    - SOD 123 diodes under switches
    [fissure-B_Cu.gbr, fissure-B_Mask.gbr, fissure-B_SilkS.gbr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]
2020-08-25 PCB fixes
    - move promicro to left edge, point USB port to top
    - move TRRS jack to top, facing right
    - move RGB to right side of T (on QWERTY)
    - cut right side
    - add OLED to top
    - add QSPI flash to left
    - cut thumb connections to 4
    - make mousebite tabs 4mm wide from 2mm
    [fissure-B_Cu.gbr, fissure-B_Mask.gbr, fissure-B_SilkS.gbr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]
2020-08-26 Change to using large breakaway holes
    [fissure.kicad_pcb]
2020-08-29 Use nice!nano
    - Add nice!nano symbols and footprints
    - Move DQ2,3 to extra pins (to leave room for future analog stick?)
    - Improved a bit of general routing
    [fissure.kicad_pcb, fissure.sch]
2020-08-29 Added needed files for nrf52 QMK
    But ...
    - Keys will get repeated when combo is enabled
    - NFC pins (0.09 and 0.10) will not work
    [config.h]
2020-10-08 Printed version (20 key steno + Qwerty) Y22
    [fissure-B_Cu.gbr, fissure-B_Mask.gbr, fissure-B_SilkS.gbr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]
2020-10-08 Add steno files; OLED not working for unknown reasons
    [config.h]
2020-10-08 Correct SDA and SCL pins on promicro in schematics and board
    [fissure.kicad_pcb, fissure.sch]
2020-12-23 Clean up design files
    [fissure.kicad_pcb, fissure.sch]
2021-01-07 Add pimoroni trackball (glued trackball to the right side)
2021-05-03 update pcb
    [fissure.kicad_pcb, fissure.sch]
2021-05-03 Use new switch footprint
    [fissure.kicad_pcb, fissure.sch]
2021-05-03 Use holyiot 18010 + USB C
    [fissure.kicad_pcb, fissure.sch]
2021-05-03 Remove old Gerbers
    [fissure-B_Cu.gbr, fissure-B_Mask.gbr, fissure-B_SilkS.gbr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]
2021-05-03 Switch cuts battery as input but still charges
    [fissure-B_Cu.gbr, fissure-B_Mask.gbr, fissure-B_SilkS.gbr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]
2021-05-03 Revision 1
    [fissure-B_Cu.gbr, fissure-B_Mask.gbr, fissure-B_SilkS.gbr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]
2021-07-07 Production version
    - make key spacing tighter on columns, squeeze to 15mm
    - squeeze key spacing on index columns also
    - generate gerbers separately and PCBA files
    - use kicad nightly
    [fissure-B_Cu.gbr, fissure-B_Mask.gbr, fissure-B_SilkS.gbr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]
2023-10-30 stagger update
    - middle 2 mm up
    - outer index flat with home
    - narrower pinky columns
    [3.2.kicad_pcb, fissure.kicad_pcb, fissure.kicad_sch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]
2023-10-30 pcb, case
    [fissure.kicad_pcb]
2023-10-30 larger vias
    [fissure.kicad_pcb]
2023-10-30 break out points
    [fissure.kicad_pcb, fissure.kicad_sch, left-switches.kicad_sch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]
2023-10-30 v3.3 production
    [fissure.kicad_pcb, left-switches.kicad_sch, right-switches.kicad_sch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]
